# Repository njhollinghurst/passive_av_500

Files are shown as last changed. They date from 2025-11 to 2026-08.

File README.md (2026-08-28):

# Passive A/V example circuit for Raspberry Pi 500

This simple circuit demonstrates composite video and audio out from Raspberry Pi 5 series computers, using only passive components (it cannot produce composite video from Raspberry Pi 400 or earlier models).  Audio quality is limited: some power supply noise may be audible. The circuit is nevertheless useful for less-demanding applications.

This is not an official product. It has not undergone regulatory testing. But you can make and adapt it.

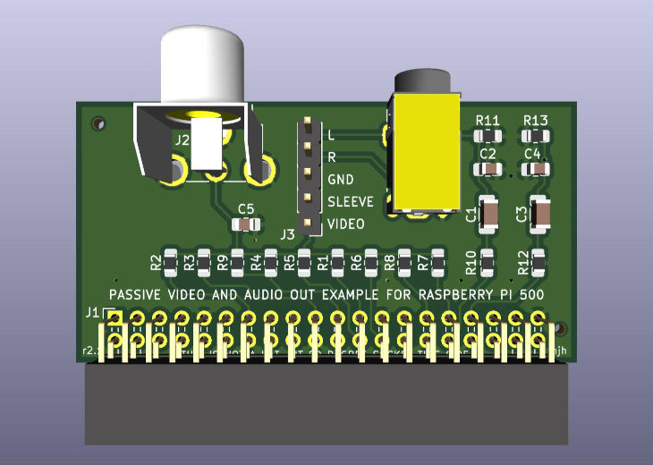
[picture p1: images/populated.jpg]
Rendered image of PCB


The board was designed using KiCad 9.0. Production files were generated using the JLCPCB plugin. They are provided without any warranty of correctness or manufacturability.

## Quick instructions

 * Ensure you can log in remotely, in case you end up with no display.
 * `dtoverlay=vc4-drm-kms-v3d,composite` (or use `raspi-config` to enable composite).
 * `dtoverlay=vec-gpio-pi5,gpio27`
 * `dtoverlay=audremap,pins_12_13`
 * `power_force_3v3_pwm=1`
 * Optionally, set a video mode in `cmdline.txt` (the default will be 704x432i NTSC).
 * Power off before connecting anything.
 * Connect to Raspberry Pi 500 or 500+, ensuring connector is centrally aligned and covers all header pins! Component side up.
 * or install vertically on a Raspberry Pi 5 or CM5IO header, with component side facing towards the Raspberry Pi's HDMI ports.
 * To get both audio and video through the jack socket, connect a jumper between VIDEO and SLEEVE pins.
 * Unplug HDMI before booting with composite video enabled.

No picture? You might not have the new overlay. Type this (after Ctrl-Alt-T if using the GUI):

```
   pinctrl 4-11,27 a1
```

## Circuit notes

Here is the [schematic](images/schematic.pdf).

### Video

On the RP1 chip, three copies of an 8-bit signal from the VEC (video encoder) can be brought out to GPIO pins 4-27, with an optional clock on GPIO 0 (rather like DPI). It is usually clocked at 108 MHz.

Here we use a simple 7-bit resistor DAC. To improve linearity, the MSB is driven by two separate GPIOs (11 and 27).

Resistor values were chosen from JLCPCB's "Basic" range (mostly E12) to approximate the sequence (490 x 2<sup><i>n</i></sup>) - 20 &Omega;. More precise values for R5 and R7 might be 1.96 k&Omega;, 7.87 k&Omega;. All resistors should be 1%.

The output is DC-coupled with an impedance of about 125 &Omega;. Peak output is about 1.2 V into a 75 &Omega; load.

### Audio

This is a variant of the PWM filter used in some Raspberry Pi models, omitting the regulator and buffer for simplicity. Although intended for use with a TV or amplifier, it can (quietly) drive headphones with impedance &ge; 32 &Omega;.

C1, C3 are unpolarized; 10% tolerance and 10V rating are fine.

### Passive components and assembly

Only SMD passive components are listed in the [BOM](production/bom.csv) file.

If using JLCPCB assembly, select **"Tooling holes placed by user"** (or they might drill extra ones). There will be a warning that J1-J4 are missing from the BOM &mdash; this is expected.

I've used "Hand Solder" footprints (with slightly longer pads) but they should work with automated assembly too.

### Connectors

J2 is Same Sky RCJ-014, available from DigiKey. Other sockets exist with similar footprints.

J4 is Tensility 54-00174. There are other similar-shaped TRRS sockets (some bending of pins may be required).

J3 is a 5-pin header, for testing and to make the video->J4 connection optional (otherwise, headphones could short the video signal). You could hard-wire a link here to omit J2, J3 and use only J4.

J1 is a 2.54mm 2x20 right-angle (horizontal) socket (female). This unusual choice was made with Raspberry Pi 500 in mind. Do *not* fit a socket on the underside! You would have to change the layout to adapt the board to HAT form factor.

### A note on missing footprints

The repository does not include any footprint or symbol libraries. Footprints for J2 and J4 are available from SnapMagic Search, Inc.

Note that I **changed their pin numbers** to match KiCad's symbols, trimmed silkscreen at board edges, and modified KiCad's `Raspberry_Pi_2_3` symbol to separate the GND pins.

## Version history

**2.0** First published version. Added tooling holes. Tested, works well.

**2.1** Add ground plane vias. Increase audio resistors, to reduce GPIO peak current (slightly reducing audio level). Move J2 slightly.

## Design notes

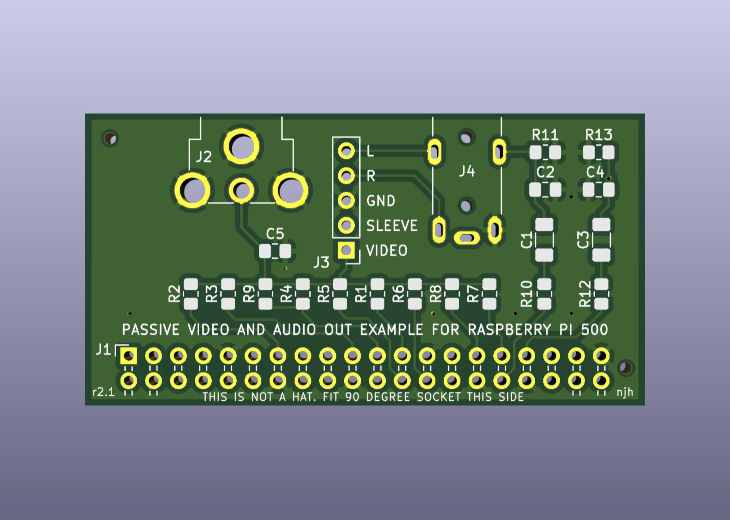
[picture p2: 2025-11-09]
images/unpopulated.jpg

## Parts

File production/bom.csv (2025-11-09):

Designator | Footprint | Quantity | Value | LCSC Part #
C1, C3 | 1206 | 2 | 22uF | C12891
C2, C4 | 0805 | 2 | 100nF | C49678
C5 | 0805 | 1 | 100pF | C1790
R1, R2, R3 | 0805 | 3 | 470R | C17710
R10, R12 | 0805 | 2 | 300R | C17617
R11, R13 | 0805 | 2 | 120R | C17437
R4 | 0805 | 1 | 1K | C17513
R5 | 0805 | 1 | 2K | C17604
R6 | 0805 | 1 | 3.9K | C17614
R7 | 0805 | 1 | 8.2K | C17828
R8 | 0805 | 1 | 15K | C17475
R9 | 0805 | 1 | 22K | C17560

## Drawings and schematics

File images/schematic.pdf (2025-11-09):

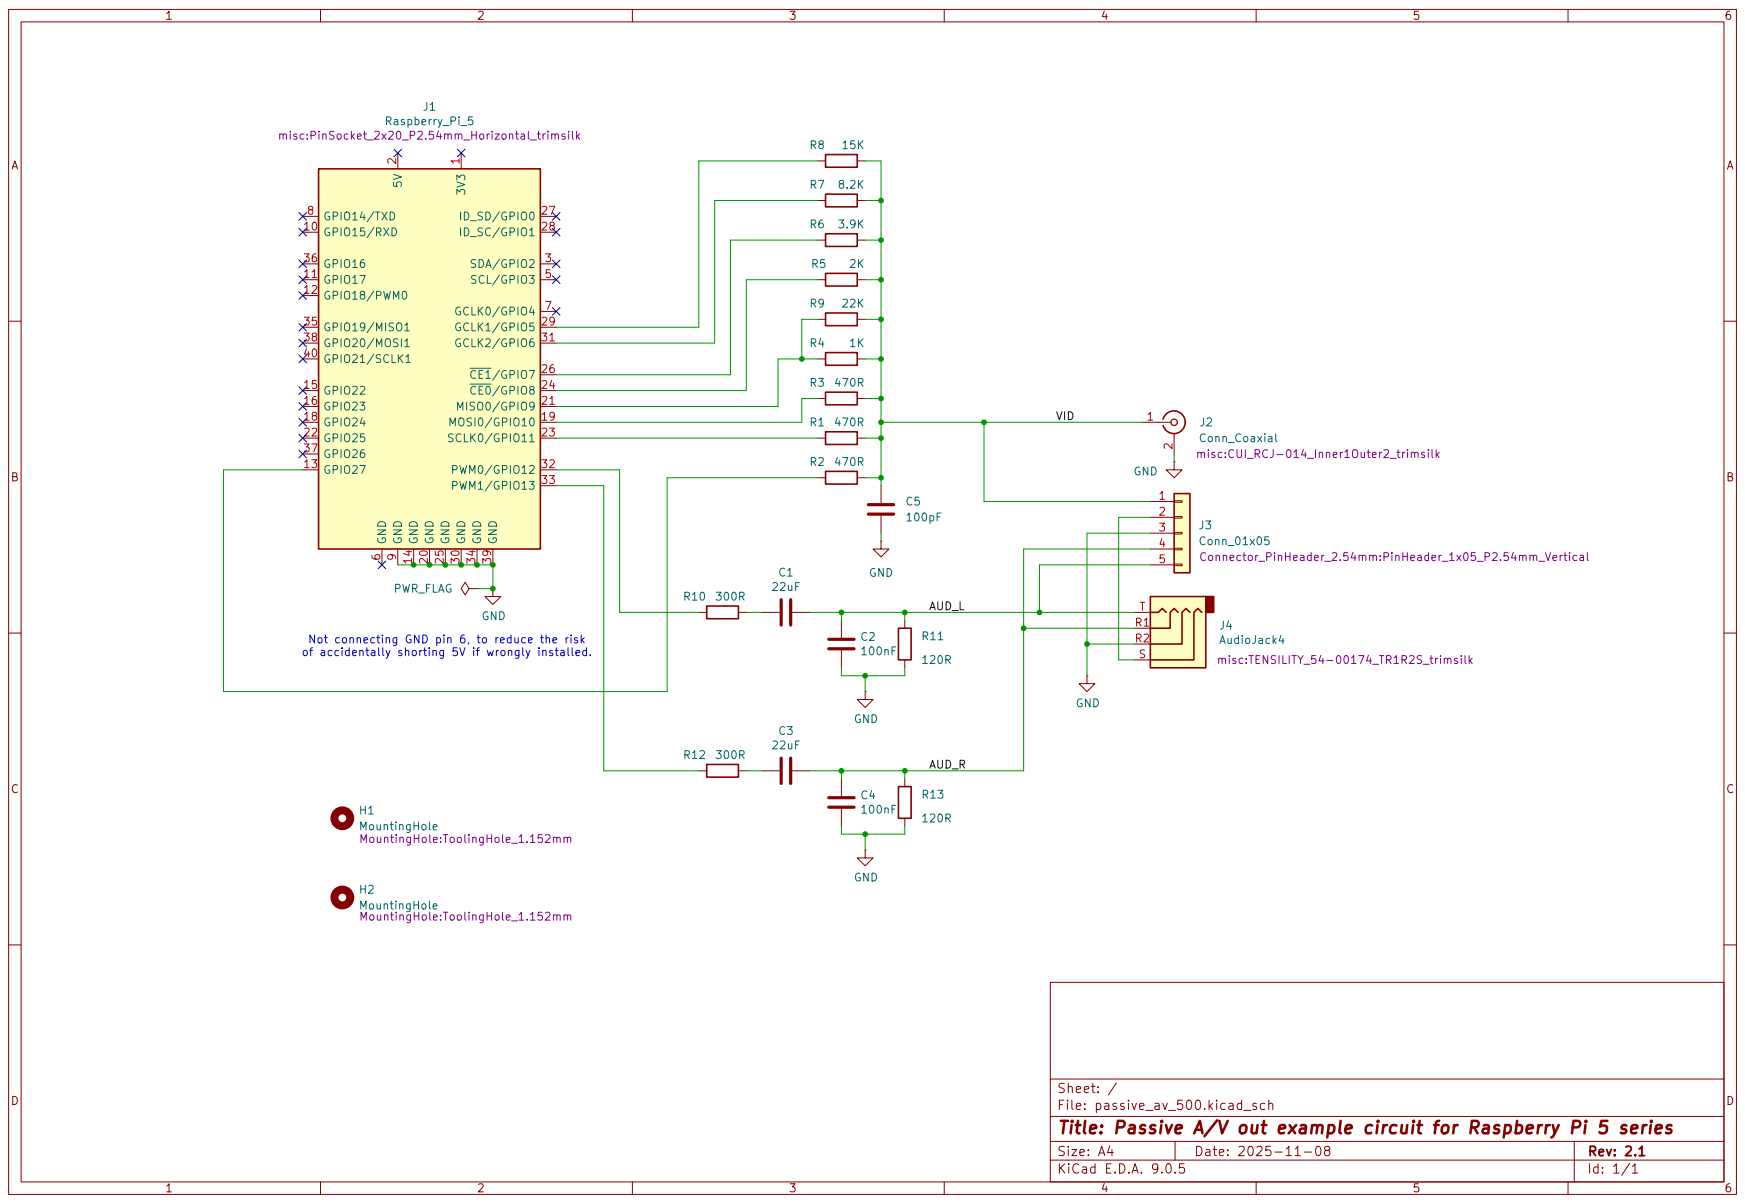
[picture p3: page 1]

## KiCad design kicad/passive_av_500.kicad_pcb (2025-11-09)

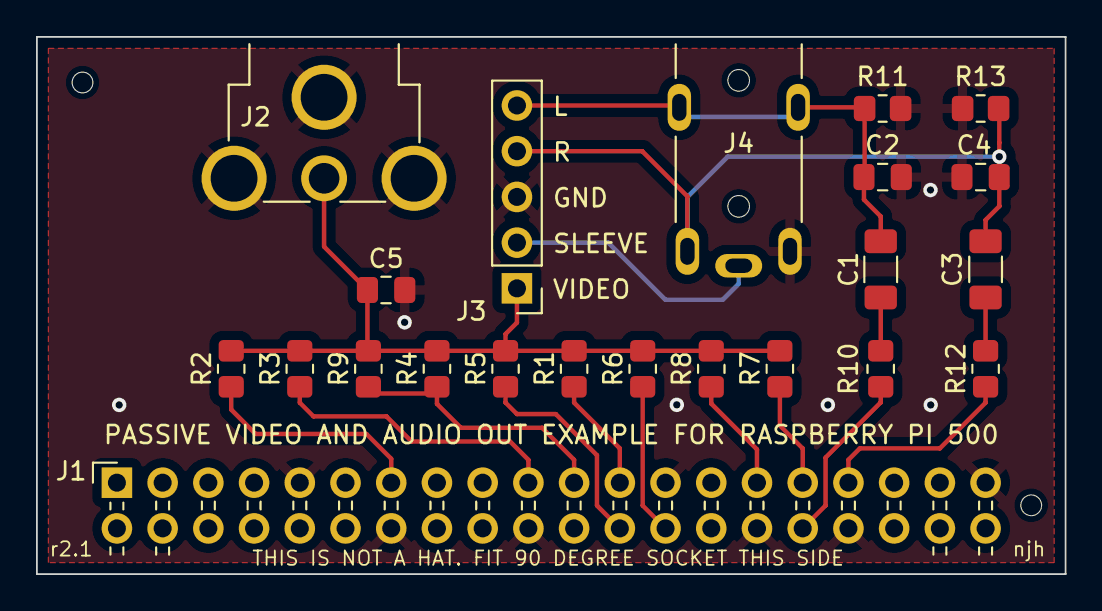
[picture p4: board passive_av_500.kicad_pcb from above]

Board: 2 copper layers, 57.1 x 29.8 mm, 24 parts (0 on the bottom side), 17 nets.

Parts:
C1, C3: 22uF; C_1206_3216Metric_Pad1.33x1.80mm_HandSolder
C2, C4: 100nF; C_0805_2012Metric_Pad1.18x1.45mm_HandSolder
C5: 100pF; C_0805_2012Metric_Pad1.18x1.45mm_HandSolder
H1, H2: MountingHole; ToolingHole_1.152mm
J1: Raspberry_Pi_5; PinSocket_2x20_P2.54mm_Horizontal_trimsilk
J2: Conn_Coaxial; CUI_RCJ-014_Inner1Outer2_trimsilk
J3: Conn_01x05; PinHeader_1x05_P2.54mm_Vertical
J4: AudioJack4; TENSILITY_54-00174_TR1R2S_trimsilk
R1, R2, R3: 470R; R_0805_2012Metric_Pad1.20x1.40mm_HandSolder
R4: 1K; R_0805_2012Metric_Pad1.20x1.40mm_HandSolder
R5: 2K; R_0805_2012Metric_Pad1.20x1.40mm_HandSolder
R6: 3.9K; R_0805_2012Metric_Pad1.20x1.40mm_HandSolder
R7: 8.2K; R_0805_2012Metric_Pad1.20x1.40mm_HandSolder
R8: 15K; R_0805_2012Metric_Pad1.20x1.40mm_HandSolder
R9: 22K; R_0805_2012Metric_Pad1.20x1.40mm_HandSolder
R10, R12: 300R; R_0805_2012Metric_Pad1.20x1.40mm_HandSolder
R11, R13: 120R; R_0805_2012Metric_Pad1.20x1.40mm_HandSolder

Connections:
/AUD_L: C1.2, C2.1, J3.5, J4.T, R11.1
/AUD_R: C3.2, C4.1, J3.4, J4.R1, R13.1
/VID: C5.1, J2.1 (In), J3.1, R1.2, R2.2, R3.2, R4.2, R5.2, R6.2, R7.2, R8.2, R9.2
GND: C2.2, C4.2, C5.2, J1.9 (GND), J1.14 (GND), J1.20 (GND), J1.25 (GND), J1.30 (GND), J1.34 (GND), J1.39 (GND), J2.2 (Ext), J3.3, J4.R2, R11.2, R13.2
unnamed: C1.1, R10.2
unnamed: C3.1, R12.2
unnamed: J1.29 (GCLK1/GPIO5), R8.1
unnamed: J1.31 (GCLK2/GPIO6), R7.1
unnamed: J1.13 (GPIO27), R2.1
unnamed: J1.21 (MISO0/GPIO9), R4.1, R9.1
unnamed: J1.19 (MOSI0/GPIO10), R3.1
unnamed: J1.32 (PWM0/GPIO12), R10.1
unnamed: J1.33 (PWM1/GPIO13), R12.1
unnamed: J1.23 (SCLK0/GPIO11), R1.1
unnamed: J1.24 (~CE0/GPIO8), R5.1
unnamed: J1.26 (~CE1/GPIO7), R6.1
unnamed: J3.2, J4.S

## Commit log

2025-10-29 Candidate files for "Rev 2" prototype - not yet tested
    [passive_av_500.kicad_pcb, passive_av_500.kicad_sch]
2025-10-29 Add some images generated by KiCad
2025-10-30 Add "tooling holes" and reconnect J1 pin 39 to improve GND plane
    [passive_av_500.kicad_pcb, passive_av_500.kicad_sch]
2025-10-30 Add production files
    [bom.csv, designators.csv, positions.csv]
2025-11-06 Add vias to ground planes
    Mainly to shorten the return current paths of C2, C4 and C5.
    [passive_av_500.kicad_pcb]
2025-11-09 Candidate "rev 2.1" version
    Increase R10,R12 and R11,R13 to 300R and 120R. This will slightly
    reduce audio level, but ensures peak GPIO current is below 12mA
    and total can't exceed 50mA (even if all A/V outputs are shorted).
    Update README.md, images and production files.
    [bom.csv, passive_av_500.kicad_pcb, passive_av_500.kicad_sch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]
2026-10-09 Candidate through-hole version th-1.0 (UNTESTED)
    Capacitor types and values tweaked for availability.
    PCB redesigned to use all through-hole components.
    Remove LCSC part numbers, which were SMD ones.
    (This version is intended for hand assembly.)
    Not yet fabricated or tested!
2026-10-24 Remove F.Paste and F.Adhesive layers, not needed for through-hole
2026-10-24 Change C1, C3 footprint from 2.5mm to 2.0mm pin spacing
    As this seems to be the more common footprint for low-voltage
    22uF electrolytic capacitors. Move C1, C3 slightly on the board.
    Remake their connections and re-do copper fill.
2026-10-24 Change date and revision in schematic, PCB and Silkscreen (th-1.1)
2026-10-31 Update board images for candidate version th-1.1
